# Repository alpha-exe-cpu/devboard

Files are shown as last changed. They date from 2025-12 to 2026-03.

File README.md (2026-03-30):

# α EZDEV Devboard
A custom development board based on the RP2040 microcontroller, designed for straightforward prototyping and hardware experimentation.

I designed this Raspberry Pi Pico clone to have a cleaner hardware setup for custom sensor nodes and Home Assistant integrations. It is a fully functional RP2040 development board that runs standard firmware like MicroPython, CircuitPython, and C/C++. For modern convenience, I upgraded the connector to USB Type-C and swapped the standard indicator light for a WS2812B RGB LED.

## Specifications
* **Microcontroller:** RP2040 (Dual-core ARM Cortex-M0+)
* **I/O:** 30 GPIO pins broken out
* **Connector:** USB Type-C
* **Storage:** External QSPI Flash
* **Indicator:** WS2812B-2020 RGB LED connected to GPIO 25

## Firmware Installation
To get CircuitPython running and utilize the onboard NeoPixel, follow these steps:

1. Download the standard Raspberry Pi Pico CircuitPython `.uf2` file from the CircuitPython website.
2. Hold down the BOOTSEL button on the board while plugging it into your computer via USB-C.
3. Copy the downloaded `.uf2` file to the `RPI-RP2` drive that mounts on your computer. The board will automatically reboot and remount as `CIRCUITPY`.
4. Download the Adafruit CircuitPython Library Bundle. Extract the folder, locate the `neopixel.mpy` file, and copy it into the `lib` folder on your new `CIRCUITPY` drive.

## Hardware Design

### PCB Layout


### 3D Renders
**Front**


**Back**


### Schematic


## NeoPixel Usage
Because the standard LED was replaced with a WS2812B NeoPixel, you must drive it as a single-pixel strip on Pin 25.

**CircuitPython Example (`code.py`):**
```python
import board
import neopixel

# Initialize the NeoPixel on GPIO 25
pixel = neopixel.NeoPixel(board.GP25, 1)

# Set the LED to red
pixel.fill((255, 0, 0))
```

## Credits
This project was built following Kai Pierra's guide on Hack Club Blueprint. Check out the original guide here: [Blueprint Starter Project: Devboard](https://blueprint.hackclub.com/starter-projects/devboard)

## Bill of Materials
| Designator | Footprint | Quantity | Value | LCSC Part # |
| :--- | :--- | :--- | :--- | :--- |
| BT1 | PinHeader_1x02_P2.54mm_Vertical | 1 | Battery | DNP |
| C1, C10 | 402 | 2 | 1uF | [C52923](https://www.lcsc.com/search?q=C52923) |
| C11, C12, C17, C2, C3, C4, C5, C6, C7, C8, C9 | 402 | 11 | 0.1uF | [C1525](https://www.lcsc.com/search?q=C1525) |
| C13, C14 | 603 | 2 | 10uF | [C19702](https://www.lcsc.com/search?q=C19702) |
| C15, C16 | 402 | 2 | 33pF | [C1562](https://www.lcsc.com/search?q=C1562) |
| D1 | LED_WS2812B-2020_PLCC4_2.0x2.0mm | 1 | WS2812B-2020 | [C965555](https://www.lcsc.com/search?q=C965555) |
| J1 | USB_C_Receptacle_HRO_TYPE-C-31-M-12 | 1 | USB_C_Receptacle_USB2.0_14P | [C165948](https://www.lcsc.com/search?q=C165948) |
| J2, J3 | PinHeader_1x20_P2.54mm_Vertical | 2 | Conn_01x20 | DNP |
| J4 | PinHeader_1x03_P2.54mm_Vertical | 1 | Conn_01x03 | DNP |
| R1, R2 | 402 | 2 | 5.1K | [C25905](https://www.lcsc.com/search?q=C25905) |
| R3, R4 | 402 | 2 | 27 | [C25100](https://www.lcsc.com/search?q=C25100) |
| R5, R6 | 402 | 2 | 1K | [C11702](https://www.lcsc.com/search?q=C11702) |
| R7 | 402 | 1 | 10K | [C25744](https://www.lcsc.com/search?q=C25744) |
| R8 | 603 | 1 | 470R | [C114669](https://www.lcsc.com/search?q=C114669) |
| R9 | 603 | 1 | 2k | [C22977](https://www.lcsc.com/search?q=C22977) |
| SW1 | SW_Push_SPST_NO_Alps_SKRK | 1 | SW_Push | [C720477](https://www.lcsc.com/search?q=C720477) |
| U1 | QFN-56-1EP_7x7mm_P0.4mm_EP3.2x3.2mm | 1 | RP2040 | [C2040](https://www.lcsc.com/search?q=C2040) |
| U2 | SOT-23 | 1 | MCP1700x-330xxTT | [C39051](https://www.lcsc.com/search?q=C39051) |
| U3 | SOT-23-5 | 1 | MCP73831-2-OT | [C14879](https://www.lcsc.com/search?q=C14879) |
| U4 | Winbond_USON-8-1EP_3x2mm_P0.5mm_EP0.2x1.6mm | 1 | W25Q16JVUXIQ TR | [C2843335](https://www.lcsc.com/search?q=C2843335) |
| Y1 | Crystal_SMD_3225-4Pin_3.2x2.5mm | 1 | 12 MHz | [C9002](https://www.lcsc.com/search?q=C9002) |

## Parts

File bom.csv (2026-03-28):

Designator | Footprint | Quantity | Value | LCSC Part #
BT1 | PinHeader_1x02_P2.54mm_Vertical | 1 | Battery | DNP
C1, C10 | 402 | 2 | 1uF | C52923
C11, C12, C17, C2, C3, C4, C5, C6, C7, C8, C9 | 402 | 11 | 0.1uF | C1525
C13, C14 | 603 | 2 | 10uF | C19702
C15, C16 | 402 | 2 | 33pF | C1562
D1 | LED_WS2812B-2020_PLCC4_2.0x2.0mm | 1 | WS2812B-2020 | C965555
J1 | USB_C_Receptacle_HRO_TYPE-C-31-M-12 | 1 | USB_C_Receptacle_USB2.0_14P | C165948
J2, J3 | PinHeader_1x20_P2.54mm_Vertical | 2 | Conn_01x20 | DNP
J4 | PinHeader_1x03_P2.54mm_Vertical | 1 | Conn_01x03 | DNP
R1, R2 | 402 | 2 | 5.1K | C25905
R3, R4 | 402 | 2 | 27 | C25100
R5, R6 | 402 | 2 | 1K | C11702
R7 | 402 | 1 | 10K | C25744
R8 | 603 | 1 | 470R | C114669
R9 | 603 | 1 | 2k | C22977
SW1 | SW_Push_SPST_NO_Alps_SKRK | 1 | SW_Push | C720477
U1 | QFN-56-1EP_7x7mm_P0.4mm_EP3.2x3.2mm | 1 | RP2040 | C2040
U2 | SOT-23 | 1 | MCP1700x-330xxTT | C39051
U3 | SOT-23-5 | 1 | MCP73831-2-OT | C14879
U4 | Winbond_USON-8-1EP_3x2mm_P0.5mm_EP0.2x1.6mm | 1 | W25Q16JVUXIQ TR | C2843335
Y1 | Crystal_SMD_3225-4Pin_3.2x2.5mm | 1 | 12 MHz | C9002

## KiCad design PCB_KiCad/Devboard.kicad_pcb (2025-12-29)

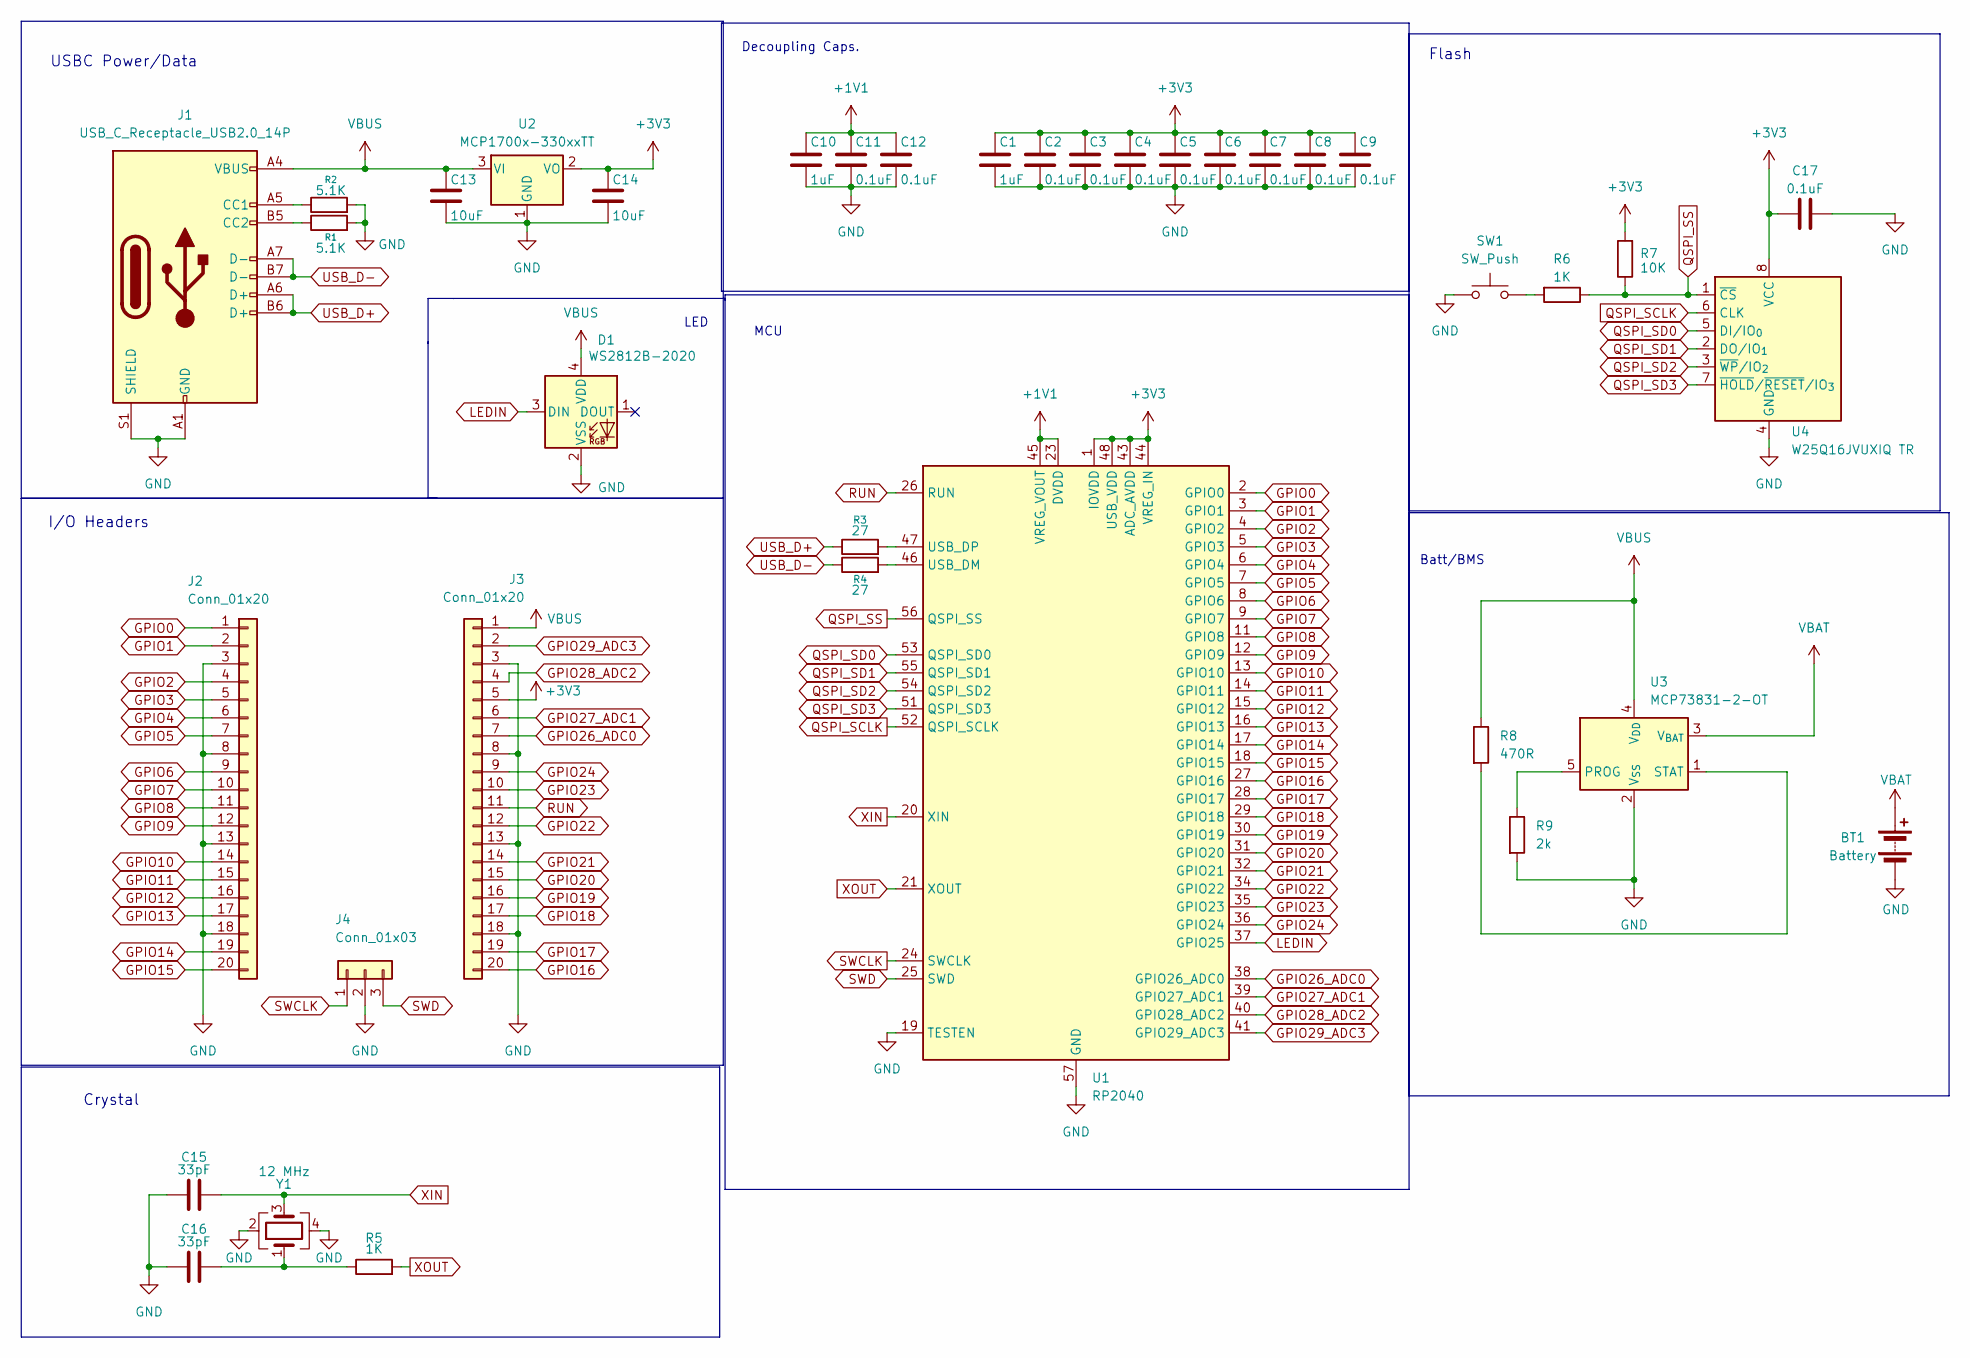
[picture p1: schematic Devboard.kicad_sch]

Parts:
BT1: Battery; PinHeader_1x02_P2.54mm_Vertical
C1, C10: 1uF; C_0402_1005Metric
C2, C3, C4, C5, C6, C7, C8, C9, C11, C12, C17: 0.1uF; C_0402_1005Metric
C13, C14: 10uF; C_0603_1608Metric
C15, C16: 33pF; C_0402_1005Metric
D1: WS2812B-2020; LED_WS2812B-2020_PLCC4_2.0x2.0mm
J1: USB_C_Receptacle_USB2.0_14P; USB_C_Receptacle_HRO_TYPE-C-31-M-12
J2, J3: Conn_01x20; PinHeader_1x20_P2.54mm_Vertical
J4: Conn_01x03; PinHeader_1x03_P2.54mm_Vertical
R1, R2: 5.1K; R_0402_1005Metric
R3, R4: 27; R_0402_1005Metric
R5, R6: 1K; R_0402_1005Metric
R7: 10K; R_0402_1005Metric
R8: 470R; R_0603_1608Metric
R9: 2k; R_0603_1608Metric
SW1: SW_Push; SW_Push_SPST_NO_Alps_SKRK
U1: RP2040; QFN-56-1EP_7x7mm_P0.4mm_EP3.2x3.2mm
U2: MCP1700x-330xxTT; SOT-23
U3: MCP73831-2-OT; SOT-23-5
U4: W25Q16JVUXIQ TR; Winbond_USON-8-1EP_3x2mm_P0.5mm_EP0.2x1.6mm
Y1: 12 MHz; Crystal_SMD_3225-4Pin_3.2x2.5mm

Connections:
+1V1: C10.1, C11.1, C12.1, U1.23 (DVDD), U1.45 (VREG_VOUT), U1.50 (DVDD)
+3V3: C1.1, C2.1, C3.1, C4.1, C5.1, C6.1, C7.1, C8.1, C9.1, C14.1, C17.1, J3.5, R7.2, U1.1 (IOVDD), U1.10 (IOVDD), U1.22 (IOVDD), U1.33 (IOVDD), U1.42 (IOVDD), U1.43 (ADC_AVDD), U1.44 (VREG_IN), U1.48 (USB_VDD), U1.49 (IOVDD), U2.2 (VO), U4.8 (VCC)
GND: BT1.2 (-), C1.2, C2.2, C3.2, C4.2, C5.2, C6.2, C7.2, C8.2, C9.2, C10.2, C11.2, C12.2, C13.2, C14.2, C15.1, C16.1, C17.2, D1.2 (VSS), J1.A1 (GND), J1.A12 (GND), J1.B1 (GND), J1.B12 (GND), J1.S1 (SHIELD), J2.3, J2.8, J2.13, J2.18, J3.3, J3.8, J3.13, J3.18, J4.2, R1.2, R2.2, R9.2, SW1.1, U1.19 (TESTEN), U1.57 (GND), U2.1 (GND), U3.2 (V_{SS}), U4.4 (GND), Y1.2, Y1.4
GPIO0: J2.1, U1.2 (GPIO0)
GPIO1: J2.2, U1.3 (GPIO1)
GPIO2: J2.4, U1.4 (GPIO2)
GPIO3: J2.5, U1.5 (GPIO3)
GPIO4: J2.6, U1.6 (GPIO4)
GPIO5: J2.7, U1.7 (GPIO5)
GPIO6: J2.9, U1.8 (GPIO6)
GPIO7: J2.10, U1.9 (GPIO7)
GPIO8: J2.11, U1.11 (GPIO8)
GPIO9: J2.12, U1.12 (GPIO9)
GPIO10: J2.14, U1.13 (GPIO10)
GPIO11: J2.15, U1.14 (GPIO11)
GPIO12: J2.16, U1.15 (GPIO12)
GPIO13: J2.17, U1.16 (GPIO13)
GPIO14: J2.19, U1.17 (GPIO14)
GPIO15: J2.20, U1.18 (GPIO15)
GPIO16: J3.20, U1.27 (GPIO16)
GPIO17: J3.19, U1.28 (GPIO17)
GPIO18: J3.17, U1.29 (GPIO18)
GPIO19: J3.16, U1.30 (GPIO19)
GPIO20: J3.15, U1.31 (GPIO20)
GPIO21: J3.14, U1.32 (GPIO21)
GPIO22: J3.12, U1.34 (GPIO22)
GPIO23: J3.10, U1.35 (GPIO23)
GPIO24: J3.9, U1.36 (GPIO24)
GPIO26_ADC0: J3.7, U1.38 (GPIO26_ADC0)
GPIO27_ADC1: J3.6, U1.39 (GPIO27_ADC1)
GPIO28_ADC2: J3.4, U1.40 (GPIO28_ADC2)
GPIO29_ADC3: J3.2, U1.41 (GPIO29_ADC3)
LEDIN: D1.3 (DIN), U1.37 (GPIO25)
unnamed: C16.2, R5.1, Y1.1
unnamed: J1.A5 (CC1), R2.1
unnamed: J1.B5 (CC2), R1.1
unnamed: R6.2, SW1.2
unnamed: R4.2, U1.46 (USB_DM)
unnamed: R3.2, U1.47 (USB_DP)
unnamed: R9.1, U3.5 (PROG)
unnamed: R8.2, U3.1 (STAT)
QSPI_SCLK: U1.52 (QSPI_SCLK), U4.6 (CLK)
QSPI_SD0: U1.53 (QSPI_SD0), U4.5 (DI/IO_{0})
QSPI_SD1: U1.55 (QSPI_SD1), U4.2 (DO/IO_{1})
QSPI_SD2: U1.54 (QSPI_SD2), U4.3 (~WP/IO_{2})
QSPI_SD3: U1.51 (QSPI_SD3), U4.7 (~HOLD/~RESET/IO_{3})
QSPI_SS: R6.1, R7.1, U1.56 (QSPI_SS), U4.1 (~CS)
RUN: J3.11, U1.26 (RUN)
SWCLK: J4.1, U1.24 (SWCLK)
SWD: J4.3, U1.25 (SWD)
USB_D+: J1.A6 (D+), J1.B6 (D+), R3.1
USB_D-: J1.A7 (D-), J1.B7 (D-), R4.1
VBAT: BT1.1 (+), U3.3 (V_{BAT})
VBUS: C13.1, D1.4 (VDD), J1.A4 (VBUS), J1.A9 (VBUS), J1.B4 (VBUS), J1.B9 (VBUS), J3.1, R8.1, U2.3 (VI), U3.4 (V_{DD})
XIN: C15.2, U1.20 (XIN), Y1.3
XOUT: R5.2, U1.21 (XOUT)

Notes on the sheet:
Flash
I/O Headers
Decoupling Caps.
LED
MCU
Batt/BMS
Crystal
USBC Power/Data

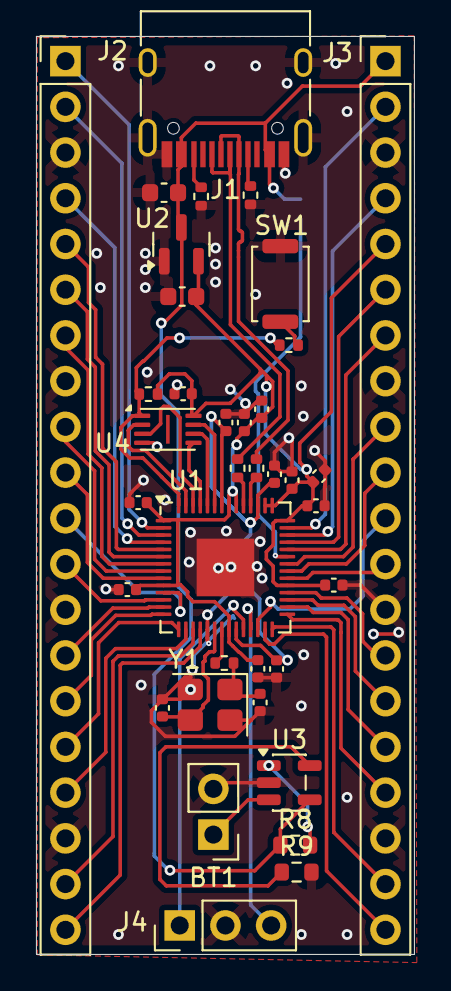
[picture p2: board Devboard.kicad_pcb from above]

Board: 2 copper layers, 21.0 x 51.0 mm, 38 parts (1 on the bottom side), 56 nets.
